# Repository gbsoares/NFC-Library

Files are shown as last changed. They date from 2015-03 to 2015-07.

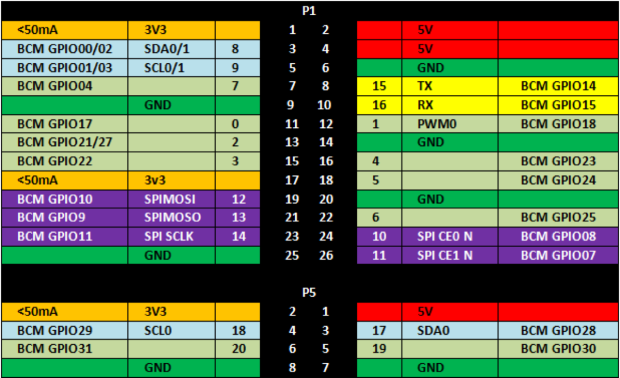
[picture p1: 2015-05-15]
gpio-descriptions-rpi1.png

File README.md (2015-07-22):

## NFC-Library
This is the project description for an NFC book management system that I built for my office.
It uses a Raspberry Pi connected to an NFC reader (PN532) to read Mifare NFC tags on the books that we have in our Engineering Library.

The motivation for this project came about when I purchased a large number of books for the Device Engineering team at Alarm.com and wanted to have a way to be able to track the state of the books. I decided that an easy way to do so would be to use and NFC tag reader which would allow me to scan the books each time they were either checked in or checked out from the library.

A high-level description of the project can be found on my [website](http://gabrielsoares.com/projects/electronics/nfc_library.html).

## Hardware & Software Components
I wanted the whole system to be self-contained and small enough to be able to mount to the bookshelves so I decided to use a Raspberry Pi and an Adafruit PN532 NFC/RFID controller board. 

The Raspberry Pi is running a Raspian Wheezy distribution onto which I have installed MySQL and the Python binding library.

I have also built an enclosure for the system out of wood and acrylic using a laser cutter (drawings included in .dwg file).

The physical connections between the Raspberry Pi, NFC reader, buttons, and LEDs are summarized in the following table:

RPi Pin # | RPi Pin Name | Connected To:
--------- | ------------ | -------------
2 | 5V | 5.0V on NFC
6 | GND | GND on NFC
8 | TX | TXD on NFC
10 | RX | RXD on NFC
12 | BCM GPIO18 | Check-Out Button
16 | BCM GPIO23 | Check-In Button
7 | BCM GPIO04 | Red LED
22 | BCM GPIO25 | Yellow LED
15 | BCM GPIO22 | Green LED
25 | GND | LEDs (cathode)

[RPi 1 GPIO Descriptions](https://github.com/gbsoares/NFC-Library/blob/master/gpio-descriptions-rpi1.png)

[RPi 2 GPIO Descriptions](https://github.com/gbsoares/NFC-Library/blob/master/gpio-descriptions-rpi2.png)

## Installation

### libnfc
The first step in connecting the Raspberry Pi to the PN532 board is to install the [libnfc library](http://nfc-tools.org/index.php?title=Main_Page). I have copied the instructions from [Adafruit](https://learn.adafruit.com/adafruit-nfc-rfid-on-raspberry-pi/overview) in case they change their page in the future. Their explanation is more detailed so I would recommend following their installation process.
* Free up UART on the RPi by going into `$ sudo raspi-config`, selecting **option 7** (Serial), and checking option to **No**. Reboot RPi.
* Go to [this link](https://bintray.com/nfc-tools/sources/libnfc) and download the latest stable release of libnfc tar file. You then want to extract uncompress and extract the contents of the .tar file (in the commands listed below, replace `libnfc-libnfc-1.7.0` with the appropriate file name from your download.
* Once you have extracted the files you need to setup libnfc for the Raspberry Pi by moving the uart config file for RPi into the correct folder `/etc/nfc/device.d/`.
```
$ cd libnfc-libnfc-1.7.0
$ sudo mkdir /etc/nfc
$ sudo mkdir /etc/nfc/devices.d
$ sudo cp contrib/libnfc/pn532_uart_on_rpi.conf.sample /etc/nfc/devices.d/pn532_uart_on_rpi.conf
```
* On the file we just moved you want to make a small edit by opening the file on the nano editor:
```
sudo nano /etc/nfc/devices.d/pn532_uart_on_rpi.conf
```
And including the line `allow_instrusive_scan = true` at the end. Save and exit.
* We now need to configure and build the project by running the following commands (note: these can take a while to complete):
```
$ sudo apt-get install autoconf
$ sudo apt-get install libtool
$ sudo apt-get install libpcsclite-dev libusb-dev
$ autoreconf -vis
$ ./configure --with-drivers=pn532_uart --sysconfdir=/etc --prefix=/usr
```
```
$ sudo make clean
$ sudo make install all
```
You can test that the installation was done successfully by running `$ nfc-list`. You should see some text that says: "Connected to NFC Reader: ...".

### MySQL
The next step is to install MySQL on the Raspberry Pi along with the Python bindings so that we can modify our database from the Python scripts. I mostly followed the steps outlined [here](http://raspberrywebserver.com/sql-databases/using-mysql-on-a-raspberry-pi.html) to do so.
* To install MySQL and the Python bindings run:
```
sudo apt-get install mysql-server python-mysqldb
```
* You then want to create a database that will hold the library items. I created a database containing three tables following the format below:
```
BOOKLIST TABLE:
+---------------+------------+------+-----+---------+----------------+
| Field         | Type       | Null | Key | Default | Extra          |
+---------------+------------+------+-----+---------+----------------+
| row           | int(11)    | NO   | PRI | NULL    | auto_increment |
| nfc_id        | bigint(20) | YES  |     | NULL    |                |
| book_title    | text       | YES  |     | NULL    |                |
| book_author   | text       | YES  |     | NULL    |                |
| status        | tinyint(1) | YES  |     | NULL    |                |
| date          | date       | YES  |     | NULL    |                |
| user          | int(11)    | YES  |     | NULL    |                |
| num_check_out | int(11)    | YES  |     | 0       |                |
+---------------+------------+------+-----+---------+----------------+

USERS TABLE: 
+-----------------------+------------+------+-----+---------+----------------+
| Field                 | Type       | Null | Key | Default | Extra          |
+-----------------------+------------+------+-----+---------+----------------+
| row                   | int(11)    | NO   | PRI | NULL    | auto_increment |
| first_name            | text       | YES  |     | NULL    |                |
| last_name             | text       | YES  |     | NULL    |                |
| nfc_id                | bigint(20) | YES  |     | NULL    |                |
| num_books_checked_out | int(11)    | YES  |     | NULL    |                |
+-----------------------+------------+------+-----+---------+----------------+

STATISTICS:
+-----------+------------+------+-----+---------+----------------+
| Field     | Type       | Null | Key | Default | Extra          |
+-----------+------------+------+-----+---------+----------------+
| row       | int(11)    | NO   | PRI | NULL    | auto_increment |
| last_in   | bigint(20) | YES  |     | NULL    |                |
| last_out  | bigint(20) | YES  |     | NULL    |                |
| num_in    | int(11)    | YES  |     | NULL    |                |
| num_out   | int(11)    | YES  |     | NULL    |                |
| most_read | bigint(20) | YES  |     | NULL    |                |
| timestamp | datetime   | YES  |     | NULL    |                |
+-----------+------------+------+-----+---------+----------------+
```

### Python Scripts
I have added two Python scripts to this project **add_book.py** and **library.py**.
Run **add_book.py** whenever you want to add a book to the database. This script will prompt you to enter the title of the book, the author(s), and scan the NFC tag. In between each step it prompts you to make sure the correct information was enterred. There are certain variables you will want to edit in your copy depending on how you set up your database.
In the block:
```
db = MySQLdb.connect('localhost', '<username>', '<password>', '<database>')
cursor = db.cursor()
```
you will want to replace `username` and `password` with the credentials you used to set up MySQL , and `database` with the name of the database you created.

**library.py** is a script that I leave running all the time. I set a cron job that starts the script after bootup and another script that reboots the RPi every night (just in case the system gets into an undesired state and there is a way to recover from it). This script performs a couple of tasks:
* it polls the state of both the check-out and check-in buttons
* it scans for NFC tags if the buttons are pressed
* it toggles the LEDs to provide visual feedback
* updates the databases
* sends statistics to data.sparkfun.com which I can then use to display basic information about the system on my website

Both files are small and straight-forward and you should be able to easily make changes to them for your application.

####Setting up Auto-Login
I made the following edits to guarantee that the correct user automatically logged in to the system after a reboot.
```
$ sudo nano /etc/inittab
```
* scroll to the line that looks like: `1:2345:respawn:/sbin/getty 38400 tty1` and comment it out by putting a "#" in front.
* now add the following line beneath it: `1:2345:respawn:/bin/login -f pi tty1 </dev/tty1 >/dev/tty1 2>&1`
* reboot the system
```
$ sudo reboot
```

####Setting up cron job
Create a directory in your $HOME directory where you can keep any logs from the cron job:
```
$ cd ~
$ mkdir logs
```
* edit crontab so that the python script library.py begins running after bootup
```
$ sudo crontab -e
```
* this will open a crontab window in which you need to add the following at the bottom:
```
@reboot sudo python /home/pi/Desktop/library.py >/home/pi/logs/cronlog 2>&1
```
Save this file and reboot your system. When the system comes back online, make sure that the python script is running correctly by either running `$ ps -ef | grep libary` and seeing if the library script is running in the background, or by running `$ top` and looking for the python process.
You can also open file 'cronlog' in "/home/pi/logs/" and check that no critical error messages were issued (messages about GPIO not being properly cleaned up are normal and expected).

####Installing PrettyTable for add_book.py
In the Python script add_book.py I use the PrettyTable module to display all of the elements of the booklist database table before the user confirms adding the book to the database. You will get an error when trying to run add_book.py if you don't have it installed. To install using `pip`, run:
```
$ sudo pip install prettytable
```

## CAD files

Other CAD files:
library.dwg

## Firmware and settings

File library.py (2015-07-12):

#!/usr/bin/python
__author__ = 'GabrielSoares'

import RPi.GPIO as GPIO
import MySQLdb
import sys
import subprocess
import re
import time
import datetime
import httplib, urllib

'''
******************************************************************
FUNCTION DEFINITIONS:
******************************************************************
'''
        
def pushStatisticsToServer(nfc_id, check_in_or_out):
    '''
    @summary: Function gathers statistics about the library and pushes the data to data.sparkfun.com/deteamlibrary
    @param nfc_id: the nfc_id of the book we just processed
    @param check_in_or_out: 1 = checked out; 0 = checked in
    '''
    server = "data.sparkfun.com"
    publicKey = "PUBLIC_KEY_VALUE"
    fields = ["last_in","last_out","most_read","num_in","num_out"]
    data = {} #data fields which will be populated to send to the data stream site
    
    #connect to the database
    try:
        db = MySQLdb.connect('localhost', 'USERNAME', 'PASSWORD', 'DATABASE_NAME')
        cursor = db.cursor()
    except:
        db.close()
        return
    
    #last book checked in
    cursor.execute("SELECT last_in FROM statistics WHERE row='1';")
    last_in_nfcid = [(item[0]) for item in cursor.fetchall()]
    cursor.execute("SELECT book_title, book_author FROM booklist WHERE nfc_id=%s;", (str(last_in_nfcid[0])))
    last_in = [(item[0], item[1]) for item in cursor.fetchall()]
    data[fields[0]] = last_in[0][0] + " - " + last_in[0][1]
    
    #last book checked out
    cursor.execute("SELECT last_out FROM statistics WHERE row='1';")
    last_out_nfcid = [(item[0]) for item in cursor.fetchall()]
    cursor.execute("SELECT book_title, book_author FROM booklist WHERE nfc_id=%s;", (str(last_out_nfcid[0])))
    last_out = [(item[0], item[1]) for item in cursor.fetchall()]
    data[fields[1]] = last_out[0][0] + " - " + last_out[0][1]
    
    #most read book
    cursor.execute("SELECT MAX(num_check_out) as num_check_out, book_title, book_author, nfc_id FROM booklist GROUP BY book_title, book_author ORDER BY num_check_out DESC;")
    rows = [(item[0], item[1], item[2], item[3]) for item in cursor.fetchall()]
    most_read_nfcid = rows[0][3]
    most_read_book = rows[0][1] + " - " + rows[0][2]
    data[fields[2]] = most_read_book
    
    #number of books checked out
    cursor.execute("SELECT SUM(status) FROM booklist;")
    rows = [(item[0]) for item in cursor.fetchall()]
    num_books_checked_out = rows[0]
    data[fields[4]] = str(num_books_checked_out)
    
    #number of books checked in
    cursor.execute("SELECT COUNT(*) FROM booklist;")
    rows = [(item[0]) for item in cursor.fetchall()]
    num_books_checked_in = rows[0]-num_books_checked_out
    data[fields[3]] = str(num_books_checked_in)
    
    # Next, we need to encode that data into a url format:
    params = urllib.urlencode(data)
    
    # Now we need to set up our headers:
    headers = {} # start with an empty set
    # These are static, should be there every time:
    headers["Content-Type"] = "application/x-www-form-urlencoded"
    headers["Connection"] = "close"
    headers["Content-Length"] = len(params) # length of data
    headers["Phant-Private-Key"] = privateKey # private key header
    
    # Now we initiate a connection, and post the data
    c = httplib.HTTPConnection(server)
    # Here's the magic, our reqeust format is POST, we want
    # to send the data to data.sparkfun.com/input/PUBLIC_KEY.txt
    # and include both our data (params) and headers
    c.request("POST", "/input/" + publicKey + ".txt", params, headers)

    #update remaining fields in statistics table
    cursor.execute("UPDATE statistics SET num_in=%s, num_out=%s, most_read=%s WHERE row='1';",
                   (str(num_books_checked_in), str(num_books_checked_out), str(most_read_nfcid)))
    db.commit()
    cursor.close()
    db.close()
    
    
def check_book(check_status):
    '''
    @summary: Function scans for NFC tags for 10 seconds. If it finds a tag, it connects to database and updates the required fields.
    @param check_status: 1 = check out; 0 = check in
    '''
    acquiredNFC = False
    numLoops = 0
    nfc_list = nfc_ids = ""
    regex = re.compile('NFCID1\):\s*([^\n\r]*)')
    
    #scan for NFC tags by calling nfc-list subprocess...
    while acquiredNFC == False and numLoops < 10:
        #call cmd that scans NFC reader
        nfc_list = subprocess.check_output("nfc-list")
    
        #check if string "NFCID1" is present in the subprocess output
        if "NFCID1" in nfc_list:
            #use regular expression on nfc_list
            nfc_ids = regex.findall(nfc_list)
    
            #make sure we detect a single valid NFC id
            if len(nfc_ids) == 0:
                return -1
            elif len(nfc_ids) > 1:
                return -1
            else:
                acquiredNFC = True  #exit inner loop
    
        #didn't find tag on NFC reader, sleep before we try again
        else:
            time.sleep(1)
            numLoops += 1

    #exit while loop because it timed out
    if acquiredNFC == False and numLoops == 10:
        return -1
    
    #convert NFC Id string to hex array
    hexId = bytearray.fromhex(nfc_ids[0].replace(" ", ""))
    #convert hex array to a 4-byte number
    NFCID = int(hexId[0] << 24 | hexId[1] << 16 | hexId[2] << 8 | hexId[3])

    #connect to the database
    try:
        db = MySQLdb.connect('localhost', 'USERNAME', 'PASSWORD', 'DATABASE_NAME')
        cursor = db.cursor()
    except:
        db.close()
        return -1

    #make sure that the NFC id exists in the database
    ret = cursor.execute("SELECT * FROM booklist WHERE nfc_id=%s;", (str(NFCID)))
    if not ret:
        cursor.close()
        db.close()
        return -1

    rows = cursor.fetchall()
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

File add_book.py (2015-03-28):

#!/usr/bin/python
__author__ = 'GabrielSoares'

import MySQLdb
import subprocess
import time
import sys
import re
from prettytable import PrettyTable


print "******************************************************************"
print "This script is going to take you through the steps to add a new"
print "\tbook to the DE_library database."
print "******************************************************************"

#prompt user for book title...
acquiredTitle = False
while not acquiredTitle:
    title = raw_input("Enter Book Title:\n>> ")

    if not title:
        print "ERR: empty field...\n"
        continue

    confirm = raw_input("Is this correct? [y/n] '" + title + "'\n>> ")
    if confirm in ['y', 'Y', 'yes']:
        acquiredTitle = True

print "--------------"

#prompt user for book author...
acquiredAuthor = False
while not acquiredAuthor:
    author = raw_input("Enter author (comma separate if multiple authors):\n>> ")

    if not author:
        print "ERR: empty fields...\n"
        continue

    confirm = raw_input("Is this correct? [y/n] '" + author + "'\n>> ")
    if confirm in ['y', 'Y', 'yes']:
        acquiredAuthor = True


#prompt user for NFC tag
flag = False
regex = re.compile('NFCID1\):\s*([^\n\r]*)')
nfc_list = nfc_ids = ""

while not flag:
    acquiredNFC = False
    numLoops = 0

    print "--------------"
    print "Present book tag to NFC reader (timeout = 10 sec)..."
    raw_input("Press Enter to start scanning...")

    while not acquiredNFC and numLoops < 10:
        print str(10 - numLoops) + ", ",
        sys.stdout.flush()

        #call cmd that scans NFC reader
        nfc_list = subprocess.check_output("nfc-list")

        if "NFCID1" in nfc_list:
            #run regular expression on nfc_list
            nfc_ids = regex.findall(nfc_list)

            if len(nfc_ids) == 0:
                print "\nCould not find a valid NFC id... quiting..."
                sys.exit()

            elif len(nfc_ids) > 1:
                print "\nDetected multiple NFC ids... please try scanning a single one..."
                acquiredNFC = True  #exit inner loop
                flag = False        #stay on outer loop

            else:
                print "\nFound a tag!"
                acquiredNFC = True  #exit inner loop
                flag = True         #exit outer loop

        #didn't find tag on NFC reader, sleep before we try again
        else:
            time.sleep(1)
            numLoops += 1

    #ask for confirmation before running outer loop again
    if not flag:
        confirm = raw_input("\nWould you like to try scanning the RFID again? [y/n]\n>> ")
        if confirm not in ['y', 'Y', 'yes']:
            sys.exit()

#convert NFC Id string to hex array
hexId = bytearray.fromhex(nfc_ids[0].replace(" ", ""))
#convert hex array to a 4-byte number
RFID = int(hexId[0] << 24 | hexId[1] << 16 | hexId[2] << 8 | hexId[3])

#check if RFID already exists in the database
try:
    db = MySQLdb.connect('localhost', '<username>', '<password>', '<database>')
    cursor = db.cursor()
except:
    print "Unable to connect to database... exiting"
    cursor.close()
    db.close()
    sys.exit()

#check if there is already an entry with this NFC id
ret = cursor.execute("SELECT * FROM booklist WHERE nfc_id=%s;", (str(RFID)))
if ret:
    print "ERR: this NFC tag already exists in the database (" + "0x{:08X}".format(RFID) + ")"
    sys.exit()

print "--------------"
print "Let's review the information before adding to the database..."
print "Book Title: '" + title + "'"
print "Book Author: '" + author + "'"
print "NFC Id: " + "0x{:08X}".format(RFID)

#Add information into MySQL database (but don't commit yet)
'''
Table Structure:
************************
column #	|	Field Nam	|	Type
---------------------------------------------------------------
	0	|	row		|	AUTO_INCREMENT
	1	|	nfc_id		|	INT
	2	|	book_title	|	TEXT
	3	|	book_author	|	TEXT
	4	|	status		|	BOOLEAN
	5	|	date		|	DATE
	6	|	user		|	TEXT
	7	|	num_check_out	|	INT
'''
try:
    cursor.execute("INSERT INTO booklist VALUES(null, %s, %s, %s, '0', %s, null, null);",
                   (str(RFID), title, author, time.strftime('%Y-%m-%d')))
except:
    print "Unable to add to database... exiting"
    cursor.close()
    db.close()
    sys.exit()

#get the entire booklist and display it
cursor.execute("SELECT * from booklist;")
rows = cursor.fetchall()
table = PrettyTable(["row", "NFC Id", "Book Title", "Book Author", "Status", "Date", "User", "Num Check Out"])
table.align["Book Title"] = "l"     #left align
table.align["Book Author"] = "l"    #left align
for i in rows:
    table.add_row(i)
print table

confirm = raw_input("Is this information correct? [y/n]\n>> ")
if confirm not in ['y', 'Y', 'yes']:
    sys.exit()

print "Information was successfully added to database"

db.commit()
cursor.close()
db.close()
sys.exit()

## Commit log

2015-03-13 Adding CAD drawings for the enclosure
    [library 2.dwg, library.dwg]
2015-03-15 Adding python script which polls buttons, and handles check-in / check-out accordingly
    This script starts running at boot-up on the Raspberry Pi and loops
    indefinitely checking for a button press on either the check-in or
    check-out button.
2015-03-24 Updates to library.py (cleaning up code and functionality)
    - added functionality so that if both buttons are pressed at the same
    time, it will blink the IP address of the RPi (useful for SSH in
    networks where IP address can change between reboots).
    - when a book is checked-in or checked-out, send statistics to
    data.sparkfun.com (used for displaying data on website)
    [library.py]
2015-03-26 Edits to AutoCAD drawing for enclosure
    Made edits to the AutoCAD drawings for the NFC+RaspberryPi enclosure
    [library.dwg]
2015-03-26 Merged library 2.dwg into library.dwg
    Deleting library 2.dwg
    [library 2.dwg]
2015-07-12 add a delay so that we don't hog down all CPU cycles
    I profiled CPU resource usage while library.py was running and was
    surprised to see the python script was using >99% CPU resources due to
    continuously iterating over the “while True:” loop. Adding a delay so
    that the CPU has a chance to give resources to other background
    processes.
2015-07-12 Adding GPIO descriptions for the Raspberry Pi 2
